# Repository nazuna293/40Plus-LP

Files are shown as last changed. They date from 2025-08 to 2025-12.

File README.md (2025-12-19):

**40Plus-LP**は[Kz](https://x.com/kazu_dob)様が設計したオーソリニア30%キーボードです。

このページでは私が設計した40Plus-LPに取り付けできるガスケットマウントケースを公開しています。　　
Kz様から承諾を得て公開しています。  

なお、キーボード本体の購入方法やビルドガイドについては Kz様の[note記事](https://note.com/kazu_dob/n/n5ea06c3c5d62)をご覧ください。

## ケースデータのダウンロード、印刷について
3Dプリンターをお持ちの方は[プリントガイド](docs/guide_print.md)を参考に印刷してみてください。  

ビルドガイドは[こちら](docs/guide_build.md)です。

## ケースの頒布について
[BOOTH](https://booth.pm/ja/items/6587448)で頒布しています。  
※Kz様から承諾を得て頒布しています。  

ビルドガイドは[こちら](docs/guide_build.md)です。

### ケーススペック
マウント方式：ガスケットマウント  
サイズ：横  
チルト：5度  
重量：約90g  
素材：PLAフィラメント  

### ケースキット同梱品一覧
・ガスケットマウントケース 1個  
・フォームシール 4個  
・M2ネジ、ナット 4組  
・ゴム足 4個  
・ケースフォーム（オプション） 1個  

### 注意事項
ケースの積層痕や反りなどは3Dプリント品特有の仕上がりとしてご理解ください。フォームシール、ケースフォームの切り出し面の乱れや粘着テープのズレはハンドメイド部品特有の仕上がりとしてご理解ください。

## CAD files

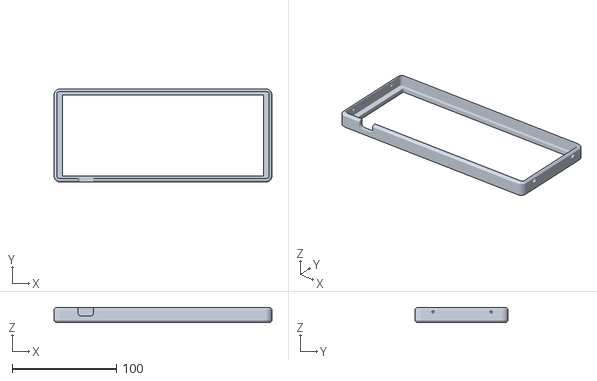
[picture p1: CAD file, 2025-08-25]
case/40Plus-LP_upper.stl
209.5 x 89.6 x 14.0

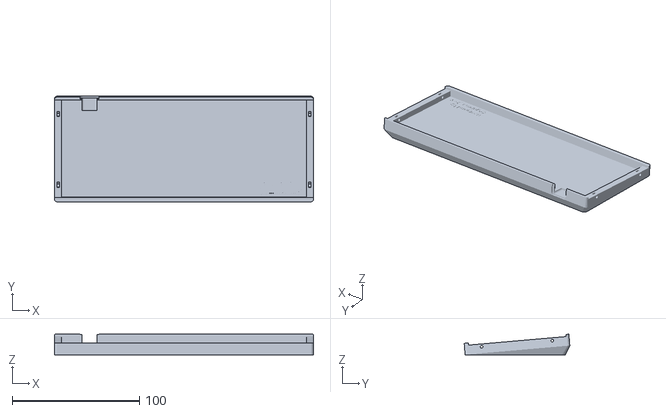
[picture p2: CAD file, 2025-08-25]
case/40Plus-LP_bottom.stl
203.5 x 83.1 x 16.3

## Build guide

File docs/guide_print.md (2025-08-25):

## プリントガイド

タイトルの印刷物を印刷する際のコツを書き留めています。ケースとして使用する際に必要なネジ等はビルドガイドに記載してあります。

造形サイズ（W210×D90×H23）にご注意ください。

おすすめの印刷設定
個人的な感想に基づき、おすすめの設定をまとめています。なお、使用機種は「Bambu Lab A1」です。

ボトムケースは底面接地
アッパーケースは上面接地
ノズル径0.4mm、積層ピッチ0.16mm
サポートなし
アッパーケースのネジ穴（頭部分）にでサポート(ツリー)をつけても良いかもしれません。

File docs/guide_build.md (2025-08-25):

## ビルドガイド

ケースキットの内容
内容物一覧
画像
※ケースフォーム(右端)はオプションです。
40Plus-LP ガスケットマウントケース ×1
フォームシール ×4
M2ネジ(長さ6mm) ×4
M2ナット ×4
ゴム足(直径7mm×厚さ1.5mm) ×4
(オプション)ケースフォーム ×1
万が一部品が不足している場合、Booth でメッセージXでDMをいただければ対応いたします。ケースフォームは40Plus-LP購入時のものを流用できますので、オプションとしています。

ケーススペック
マウント方式：ガスケットマウント
サイズ：横
チルト：5度
重量：約g
素材：PLAフィラメント

ガスケットマウントケース
画像
上面に来る『アッパーケース』と底面に来る『ボトムケース』の２つで構成されます。家庭用3Dプリンターで出力したもので、PLAという一般的な素材を使用しています。

フォームシール
基板（トッププレート）を挟み込みケースに固定するために使用します。ポロンシートを手作業で切り出して両面テープを貼り付けたものです。

M2ネジ(長さ6mm)
アッパーケースを左右からネジ止めする際に使用します。長さ6〜10mmのネジを使用できますが、長さ6mmが適切です。

M2ナット
ボトムケースに嵌め込み、アッパーケースをネジ止めする際に使用します。一般的な外径4mm、厚さ1.6mmのものです。ケースもこちらに合わせて設計しています。

ゴム足(直径7mm×厚さ1.5mm)
ボトムケースに滑り止めとして使用します。経年劣化で剥がれた場合、Amazon等で同じものを購入することができます。

COVERCORNER 100粒 人気家具 滑り止め ゴム足 緩衝 滑り止め シール 戸当たりクッション クリアー色 丸型・円形 粘着タイプ 防振・衝撃・キズ防止 (半球形 透明) (直径7mm×厚さ1.5mm (100粒セット))
amzn.asia
650円
(2025年02月12日 14:48時点 詳しくはこちら)
Amazon.co.jpで購入する
ケースフォーム
40Plus-LPを購入時のものを流用してください。オプションを利用された方には(縦mm×横mm)のサイズにカットしたものを同梱しています。

ケースキットの組み立て
40Plus-LPを分解する
ケースのネジ止めを外して、基板とケースフォームを取り外してください。キーキャップ等の取り外しは不要です。

ボトムケースの両端にナットを嵌め込む
画像
奥まで嵌め込むと左側のナットの状態になる。
ボトムケースの両端にスリットがありますので、ナットを嵌め込んでください。ナットの頂点が真上に来るように軽い力で奥まで嵌め込んでください。正しく嵌まれば左右から見た時に向こう側が見えます。

ケースの両端にフォームシールを貼り付ける
画像
ボトムケース　ナットのスリットを覆う
画像
アッパーケース　壁面に沿わせる
アッパーケースとボトムケースの両端にフォームシールを貼り付けてください。ボトムケースはナットのスリットを覆うかたちになります。

ケースフォームを敷く
画像
切り欠きを合わせる
ボトムケースとケースフォームの切り欠きを合わせて敷いてください。

ボトムケースに基板を設置する
基板をボトムケースに合わせて設置してください。
この時点で固定はありませんので置くだけになります。

アッパーケースをネジ止めする
画像
アッパーケースを押さえてネジ穴を合わせる
アッパーケースとボトムケースの切り欠きを合わせて被せます。アッパーケースを上から押して、ボトムケースのネジ穴を合わせてネジ止めしてください。ネジ穴はタイトに設計していますので、締め回すと上手く入りやすいです。

ケースが割れる可能性がありますので、ネジは締めすぎないようにしてください。ネジが入らない場合は、アッパーケースを押す力を調整して、ボトムケースのネジ穴を合わせてください。ネジを締め込んでも空回りする場合は、ナットが適切な位置にあるか確認してください。

ゴム足を貼り付ける
ボトムケースの四隅にゴム足を貼り付けます。

補足　マグネット端子
画像
マグネット端子がツライチになる
USBコネクタ保護のため、マグネット端子をおすすめします。また、マグネット端子を取り付けた方がケースの切り欠きが目立ちません。L字型、I字型ともに取り付け可能です。

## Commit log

2025-08-17 LICENSE を作成
2025-08-19 README.md を作成
2025-08-25 README.md を更新
